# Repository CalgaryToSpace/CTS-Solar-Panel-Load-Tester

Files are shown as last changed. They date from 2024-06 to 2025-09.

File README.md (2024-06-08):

# CTS-Solar-Panel-Load-Tester
A solar cell/panel testing device which places a variable load on a panel to characterize its IV/PV curve

## Description

An Arduino controls a MOSFET, acting as a resistor load, to allow varying current through the MOSFET from the solar panels. Two measures are used to monitor current - an INA219 current sensor, and a shunt resistor with an op-amp network. An ADC measures the total cell/panel voltage.

The Arduino logs the voltage/current values over UART to a computer.

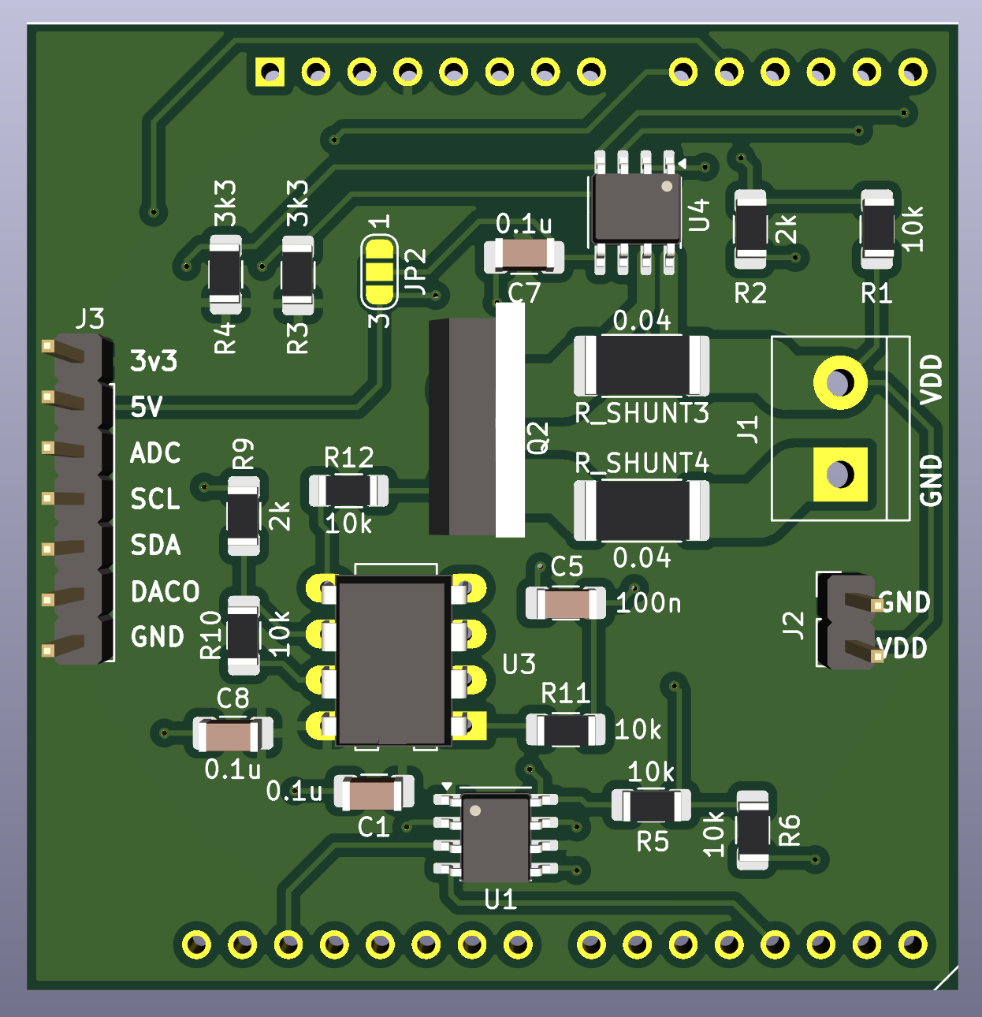
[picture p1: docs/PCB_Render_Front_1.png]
PCB Render (Front)


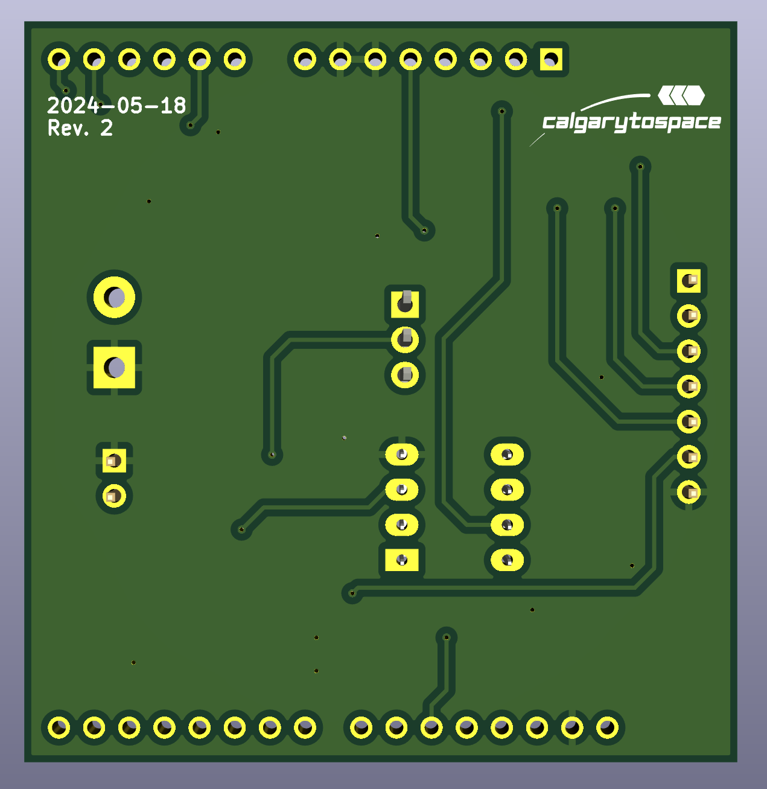
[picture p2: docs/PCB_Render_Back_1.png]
PCB Render (Back)


## Notes

* R_shunt = Full Scale Voltage / Max Expected Load Current =  40mV / 0.5A = 80mOhms, so 0.1 ohms is reasonable

## License

The software is licensed under [The Unlicense](https://choosealicense.com/licenses/unlicense/). The hardware is licensed under the [CERN Open Hardware Licence Version 2 - Permissive](https://choosealicense.com/licenses/cern-ohl-p-2.0/).

Please see the respective license documents in each sub-folder.

## Similar Projects

* **Main Reference:** https://circuitdigest.com/microcontroller-projects/adustable-electronic-dc-load-using-arduino

* https://jasper.sikken.nl/electronicload/index.html
    * Uses an [IRLZ44Z MOSFET](https://www.infineon.com/dgdl/irlz44zpbf.pdf?fileId=5546d462533600a4015356722836272a)
    * Archived on [the Wayback Machine](https://web.archive.org/web/20240229184606/https://jasper.sikken.nl/electronicload/index.html)
    
## Future Changes

* **Detect cracks in cells:** Add a MOSFET to briefly pulse a voltage across the cells and trigger an infrared camera to take a photo.

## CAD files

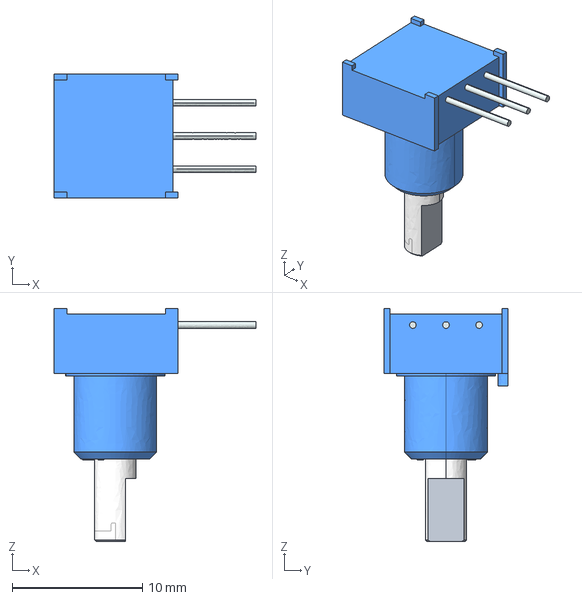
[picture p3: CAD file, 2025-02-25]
panel-tester-hardware/Project_Lib/3310c-101.stp
15.5 x 9.52 x 17.9 mm

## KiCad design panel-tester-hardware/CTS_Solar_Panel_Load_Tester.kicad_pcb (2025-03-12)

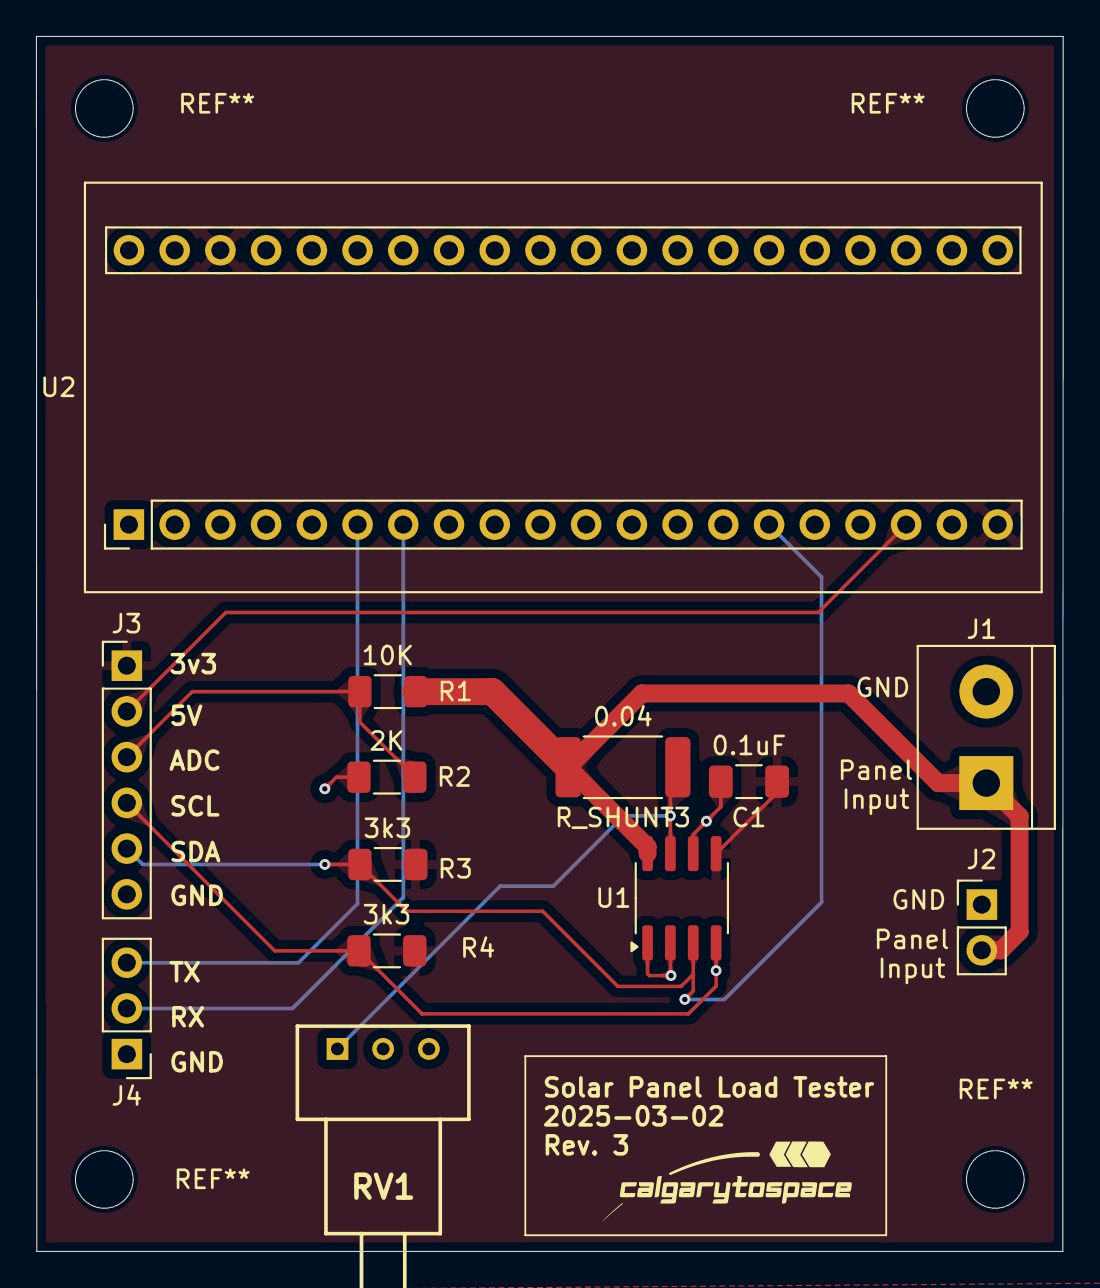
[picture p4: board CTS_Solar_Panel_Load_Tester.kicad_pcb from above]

Board: 2 copper layers, 57.0 x 67.5 mm, 13 parts (0 on the bottom side), 9 nets.

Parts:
C1: 0.1uF; C_1206_3216Metric_Pad1.33x1.80mm_HandSolder
J1: Screw_Terminal_01x02; TerminalBlock_bornier-2_P5.08mm
J2: Conn_01x02_Pin; PinHeader_1x02_P2.54mm_Vertical
J3: Conn_01x07; PinHeader_1x06_P2.54mm_Vertical
J4: Conn_01x03; PinHeader_1x03_P2.54mm_Vertical
R1: 10K; R_1206_3216Metric_Pad1.30x1.75mm_HandSolder
R2: 2K; R_1206_3216Metric_Pad1.30x1.75mm_HandSolder
R3, R4: 3k3; R_1206_3216Metric_Pad1.30x1.75mm_HandSolder
RV1: R_Potentiometer; 3310C101102L
R_SHUNT3: 0.04; R_2512_6332Metric_Pad1.40x3.35mm_HandSolder
U1: INA219AxD; SOIC-8_3.9x4.9mm_P1.27mm
U2: YAAJ_BluePill; YAAJ_BluePill_2

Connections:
+3V3: C1.1, J3.1, R3.1, R4.1, U1.5 (VS), U2.20 (3V3), U2.38 (3V3)
+5V: J3.2, U2.18 (5V)
GND: C1.2, J1.2, J2.1, J3.6, J4.1, R2.2, RV1.2, U1.1 (A1), U1.2 (A0), U1.6 (GND), U2.19 (GND), U2.39 (GND), U2.40 (GND)
MCU_ADC_SENSE: J3.3, R1.2, R2.1
MCU_I2C_SCL: J3.4, R4.2, U1.4 (SCL), U2.14 (PB6)
MCU_I2C_SDA: J3.5, R3.2, U1.3 (SDA), U2.15 (PB7)
unnamed: J4.2, U2.7 (PA10)
unnamed: J4.3, U2.6 (PA9)
V_SOLAR_INPUT_POS: J1.1, J2.2, R1.1, RV1.1, R_SHUNT3.1, R_SHUNT3.2, U1.7 (IN-), U1.8 (IN+)

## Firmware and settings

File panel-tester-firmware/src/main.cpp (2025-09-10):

#include "SPI.h"
#include "MCP_DAC.h"

// Chip select pin for MCP4921
const uint8_t PIN_MCP_CS = 10;
const uint8_t PIN_MCP_MOSI = 3;
const uint8_t PIN_MCP_CLK = 13;

// Initialize DAC: MOSI=D3, CLK=D13.
// Important note: If not using the default hardware pins (MOSI=D11, CLK=D13),
// then DO NOT call `SPI.begin()`!
MCP4921 dac(PIN_MCP_MOSI, PIN_MCP_CLK);



/// @brief Sets the DAC value to a new value.
/// @param new_value 12-bit value to set the DAC to (0 to 4095).
void set_dac_value(uint16_t new_value)
{
    if (! dac.write(new_value, 0))
    {
        Serial.println("Failed to write to DAC.");
    }
}

void setup()
{
    Serial.begin(115200);
    Serial.println("Booting...");

    // Init pin modes.
    pinMode(PIN_MCP_CS, OUTPUT);
    digitalWrite(PIN_MCP_CS, HIGH); // Disable chip select. - why are we disabling when we need the clk and data?

    pinMode(PIN_MCP_CLK, OUTPUT);
    pinMode(PIN_MCP_MOSI, OUTPUT);

    dac.begin(PIN_MCP_CS); // Set chip select pin.
    // Note: DO NOT call SPI.begin() if using software SPI (like we are).
    Serial.println("MCP_DAC Initialized");

    
    Serial.print("MCP_DAC_LIB_VERSION: ");
    Serial.println(MCP_DAC_LIB_VERSION);
    Serial.println();
    Serial.print("CHANNELS: ");
    Serial.println(dac.channels()); // Prints # of DAC channels (1)
    Serial.print("MAXVALUE: ");
    Serial.println(dac.maxValue()); // Prints max value (4095 for a 12 bit DAC)

    delay(1000);

    Serial.println("End of setup()...");
}


void loop()
{
    for (uint16_t dac_value = 0; dac_value < 4096; dac_value += 50)
    {
        set_dac_value(dac_value);
        Serial.print("dac: ");
        Serial.println(dac_value);
        delay(1000);
    }
}

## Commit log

2024-03-15 Add hardware schematic design
    [panel-tester-hardware.kicad_pcb, panel-tester-hardware.kicad_sch]
2024-04-27 Changed Schematic Files
    Modified Load Testing Schematic to use two current sensing mechanisms - (1) is the existing current sensing IC, MOSFET and shunt resistor and (2) is the new op-amp mechanism with the MOSFET and shunt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
    [constant_load.kicad_sch, panel-tester-hardware.kicad_sch]
2024-05-04 Did a lot of things
    Created board layout and completed routing
    [panel-tester-hardware.kicad_pcb, panel-tester-hardware.kicad_sch]
2024-05-04 Created production files
    Created production files
    [panel-tester-hardware.kicad_pcb]
2024-05-08 Made final slikscreen changes
    [panel-tester-hardware.kicad_pcb]
2024-05-08 Created schematic PDF
2024-05-18 Updated schematic with DAC
    Added MCP4921 for analog signal creation from Arduino PWM into the input of the Op-Amp.
    [panel-tester-hardware.kicad_sch]
2024-05-18 Assigned footprints for DAC and additional passives
    [panel-tester-hardware.kicad_sch]
2024-05-18 Completed routing and aesthetic fixes
    [panel-tester-hardware.kicad_pcb, panel-tester-hardware.kicad_sch]
2024-05-18 Created production files
    [panel-tester-hardware.kicad_pcb]
2024-06-08 Add renders to README, update schematic PDF with rev number
    [constant_load.kicad_sch, panel-tester-hardware.kicad_sch]
2024-08-19 Fix typos on schematic
    [panel-tester-hardware.kicad_sch]
2024-12-18 Firmware: support PCB Rev 2
2025-02-05 Add files via upload
    Version 2 Schematic
    [CTS_Solar_Panel_Load_Tester.kicad_sch]
2025-02-20 Fix potentiometer schematic and import custom footprint
    [CTS_Solar_Panel_Load_Tester.kicad_pcb, CTS_Solar_Panel_Load_Tester.kicad_sch]
2025-02-25 Add microcontroller breakout pins, update potentiometer footprint
    [CTS_Solar_Panel_Load_Tester.kicad_sch]
2025-02-25 PCB layout v1
    [CTS_Solar_Panel_Load_Tester.kicad_pcb]
2025-02-25 Add 3D model
    [3310c-101.stp]
2025-02-25 Add footprint file
2025-02-26 Add bluepill footprint
2025-02-26 Bluepill layout edits
    [CTS_Solar_Panel_Load_Tester.kicad_pcb, CTS_Solar_Panel_Load_Tester.kicad_sch, panel-tester-hardware.kicad_sch]
2025-02-26 Revert "Bluepill layout edits"
    This reverts commit 7404dadbf005f9dc7929b7ea0254307db19fd9e4.
    [CTS_Solar_Panel_Load_Tester.kicad_pcb, CTS_Solar_Panel_Load_Tester.kicad_sch, panel-tester-hardware.kicad_sch]
2025-02-26 Revert "Add bluepill footprint"
    This reverts commit 3df0fce7c146b90b9d7b39e29235daf38b6f8407.
2025-02-26 Bluepill footprint & layout
    [CTS_Solar_Panel_Load_Tester.kicad_pcb, CTS_Solar_Panel_Load_Tester.kicad_sch]
2025-02-26 Rename potentiometer footprint
2025-02-26 ERC/DRC fixes
    [CTS_Solar_Panel_Load_Tester.kicad_pcb, CTS_Solar_Panel_Load_Tester.kicad_sch]
2025-03-02 Schematic fixes + UART breakout header
    TODO: Confirm R_shunt value
    [CTS_Solar_Panel_Load_Tester.kicad_sch]
2025-03-03 Layout fixes, add mounting holes, silkscreen edits
    TODO: Add bypass capacitor & reroute, use thicker trace for high current path
    [CTS_Solar_Panel_Load_Tester.kicad_pcb]
2025-03-03 Add bypass capacitor
    [CTS_Solar_Panel_Load_Tester.kicad_pcb, CTS_Solar_Panel_Load_Tester.kicad_sch]
2025-03-03 1.5 mm net class for solar panel input path
    [CTS_Solar_Panel_Load_Tester.kicad_pcb]
2025-03-06 Add 1 mm net class for high current path
    [CTS_Solar_Panel_Load_Tester.kicad_pcb]
2025-05-17 Created Solar Panel LT Spice Sim
    Not finished, has variable current source to represent varied illumination with voltage source purely being a value for illumination. R1 represents leakage and R2 represents internal resistance. Needs to be put in library still.
